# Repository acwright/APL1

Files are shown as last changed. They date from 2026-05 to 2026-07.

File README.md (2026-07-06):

APL1
====

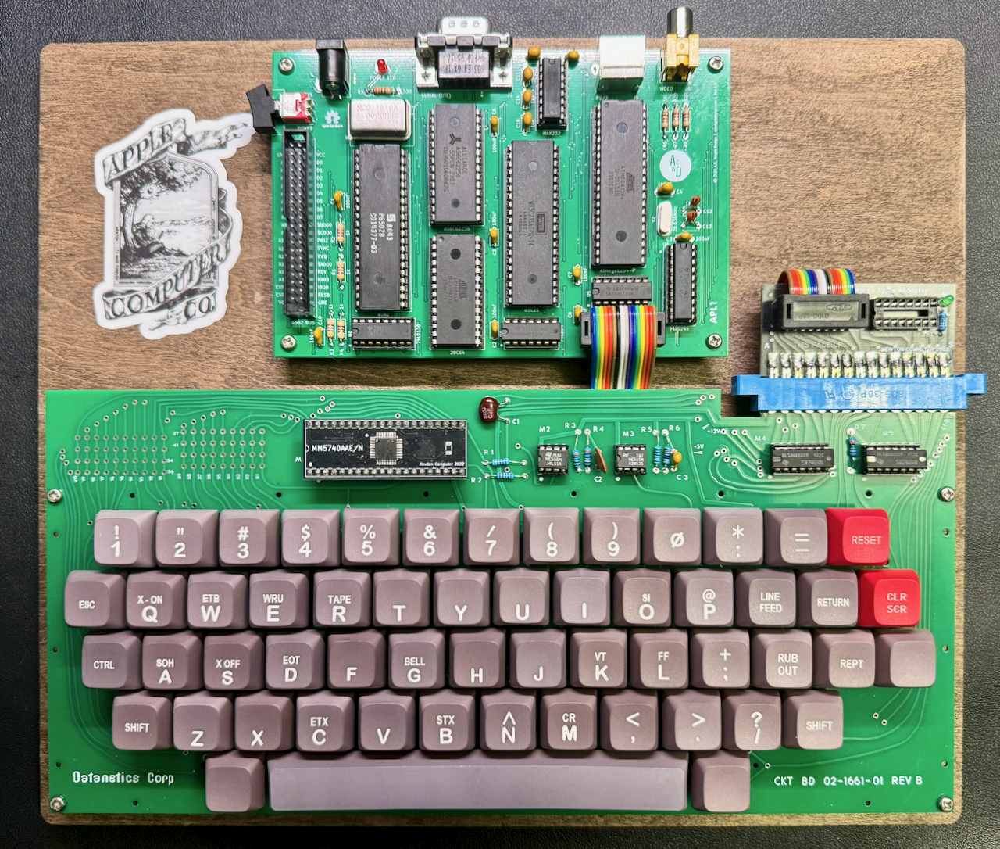
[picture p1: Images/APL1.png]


A homebrew **Apple 1** replica built around the **6502** microprocessor, with a modern microcontroller-based terminal that adds PS/2 keyboard and serial input alongside the original ASCII keyboard interface.

---

## Table of Contents

- [Overview](#overview)
- [Architecture](#architecture)
- [Hardware](#hardware)
  - [APL1 Board](#apl1-board)
    - [Revision History](#revision-history)
- [Firmware](#firmware)
  - [APL1 Controller](#apl1-controller)
  - [APL1 ROM](#apl1-rom)
  - [APL1 Terminal](#apl1-terminal)
- [CAD](#cad)
- [Production](#production)
- [Schematics](#schematics)
- [Libraries](#libraries)
- [Bill of Materials](#bill-of-materials)
- [License](#license)

---

## Overview

The **APL1** is a faithful recreation of the 1976 Apple 1 computer, rebuilt as an open-source KiCad project. It preserves the original 6502 + PIA architecture and the classic [WozMon](https://en.wikipedia.org/wiki/Woz_Monitor) firmware experience, while replacing the bulky discrete terminal section of the original with an ATmega1284 microcontroller. The MCU emulates the Apple 1 keyboard and display handshake exactly, but also exposes a PS/2 keyboard port and a serial terminal connection for modern convenience.

## Architecture

- **CPU**: MOS 6502 running at 1 MHz
- **RAM**: 32KB SRAM (AS6C62256)
- **ROM**: 8KB EEPROM (28C64) holding WozMon
- **PIA**: 65C21 — the Apple 1 keyboard/display interface
- **Terminal**: ATmega1284(P) controller emulating the original terminal handshake
- **Input**: Original ASCII keyboard header, PS/2 keyboard, and serial (RS-232) input
- **Output**: Serial terminal output, with composite video reserved for a future revision
- **Bus**: 16-bit address bus, 8-bit bidirectional data bus, standard 6502 control signals
- **Clock**: 1 MHz oscillator for the 6502; 28.63636 MHz crystal (8× NTSC colorburst) for the controller

## Hardware

This repository contains KiCad 7.0+ PCB designs for the APL1 board.

### APL1 Board
`Hardware/APL1/`

The single board hosting the 6502 CPU, memory, PIA, and the ATmega1284 terminal controller. Provides:

- **CPU**: 6502 running at 1 MHz
- **RAM**: 32KB SRAM (AS6C62256)
- **ROM**: 8KB EEPROM (28C64) preloaded with WozMon
- **PIA**: 65C21 keyboard/display interface (original Apple 1 footprint)
- **Terminal Controller**: ATmega1284(P) running APL1 Controller firmware
- **Keyboard buffer**: 74LS245 octal bus transceiver
- **Glue logic**: 74LS04, 74LS00, and 74LS138 address decoder
- **Serial**: MAX232 level shifter with DB-9 (DTE) connector
- **Input**: Original ASCII keyboard header and PS/2 keyboard connector
- **Video**: RCA composite video jack (reserved for a future firmware revision)
- **Reset**: Keyboard reset and clear controls handled by the controller
- **Power**: 5V DC via barrel jack, with power switch and indicator LED

#### Revision History

**Rev 1.1**

- Add 10k pull-down resistor `R9` for KBDCLR.
- Change pull-up resistors `R1-R4` from 1k to 4.7k.
- Add capacitor `C17` for bulk capacitance at power supply.

**Rev 1.0**

- Initial release.

## Firmware

This repository contains firmware for the terminal controller, the system ROM, and the desktop terminal application.

### APL1 Controller
`Firmware/APL1 Controller/`

[PlatformIO](https://platformio.org/)-based firmware for the ATmega1284(P) terminal controller. Provides:

- Faithful emulation of the Apple 1 keyboard and display handshake (DA / RDAB)
- Original ASCII keyboard pass-through via the 74LS245 buffer
- PS/2 keyboard input with a custom Set-2 ISR decoder mapped to Apple 1 ASCII
- Serial (RS-232) terminal input and output at 115200 8N1
- Control shortcuts for clear screen, reset, and throttle ("slow") mode
- Keyboard reset and clear button handling
- Composite video output hooks reserved for a future revision

See [Firmware/APL1 Controller/README.md](./Firmware/APL1%20Controller/README.md) for build, flash, and pin-map details.

### APL1 ROM
`Firmware/APL1 ROM/`

The system ROM image built from **WozMon**, Steve Wozniak's original Apple 1 monitor, assembled with the [cc65](https://cc65.github.io/) toolchain and burned to a 28C64 EEPROM.

See [Firmware/APL1 ROM/README.md](./Firmware/APL1%20ROM/README.md) for build and programming instructions.

### APL1 Terminal
`Firmware/APL1-Terminal/`

An [Electron](https://www.electronjs.org/) + [Vue 3](https://vuejs.org/) desktop application that provides a faithful CRT terminal experience for the APL1. Connects to the board over the DB-9 serial port at 115200 8N1 and renders output using the original Signetics 2513 character ROM glyphs. Provides:

- 40×24 character canvas rendered with the authentic Signetics 2513 font
- Selectable phosphor color: white, amber, or green
- CRT effects: phosphor glow, scanlines overlay, and screen flicker animation
- Serial port connection and disconnection (auto-detected ports)
- Keyboard input forwarded to the APL1 with Apple 1 control shortcuts (Ctrl+L clear, Ctrl+\ reset, Ctrl+T throttle)
- Built-in program loader with paced character/line sending for 20 bundled Wozmon programs
- Settings panel with per-character and per-line delay controls
- macOS (Apple Silicon DMG), Linux (AppImage / deb), and Windows (NSIS installer) distribution builds, all built locally from macOS

See [Firmware/APL1-Terminal/README.md](./Firmware/APL1-Terminal/README.md) for build and run instructions.

## CAD
`CAD/`

3D models and images for the APL1 board and its components.

## Production
`Production/`

JLCPCB-ready fabrication files, BOM, and component positions for PCB fabrication and assembly.

## Schematics
`Schematics/`

Schematics for the APL1 board.

## Libraries
`Libraries/`

Shared KiCad symbol and footprint libraries used across the APL1 hardware project.

## Bill of Materials

| Reference | Qty | Value | Description |
|---|-----|---|---|
| C1–C10 | 10 | 100nF | Disc Capacitor |
| C11, C14, C15, C16 | 4 | 1µF | Disc Capacitor |
| C12, C13 | 2 | 18pF | Disc Capacitor |
| C31 | 1 | 10uF | Electrolytic Capacitor 16v |
| D1 | 1 | POWER LED | 3.0mm Power LED |
| J2 | 1 | KEYBOARD | ASCII Keyboard Header (DIP-16) |
| J3 | 1 | SERIAL (DTE) | DB-9 Male |
| J4 | 1 | 5V DC | DC Barrel Jack |
| J5 | 1 | PS/2 | 6-pin Mini-DIN (KMDGX-6S-BS) |
| J6 | 1 | VIDEO | RCA Jack (PJRAN1X1U0XX) |
| R1–R4 | 4 | 4.7kΩ | 1/8W Resistor |
| R6 | 1 | 1kΩ | 1/8W Resistor |
| R5 | 1 | 330Ω | 1/8W Resistor |
| R7, R8 | 2 | 820Ω | 1/8W Resistor |
| R9 | 2 | 10kΩ | 1/8W Resistor |
| SW1 | 1 | POWER | SPDT Switch (400MSP1R6BLKM6QE) |
| U1 | 1 | 74LS04 | Hex Inverter |
| U2 | 1 | 6502 | 6502 CPU |
| U3 | 1 | 65C21 | PIA |
| U4 | 1 | AS6C62256 | 32KB SRAM |
| U5 | 1 | 74LS00 | Quad NAND |
| U6 | 1 | 74LS138 | 3-to-8 Decoder |
| U7 | 1 | 28C64 | 8KB EEPROM |
| U8 | 1 | 74LS245 | Octal Bus Transceiver |
| U9 | 1 | MAX232 | RS-232 Transceiver |
| U10 | 1 | ATmega1284-P | Terminal Controller MCU |
| Y1 | 1 | 1MHz | DIP-14 Oscillator |
| Y2 | 1 | 28.636MHz | Crystal |

## License

Hardware designs are released under the [CERN Open Hardware Licence Version 2 – Permissive](https://ohwr.org/cern_ohl_p_v2.txt).

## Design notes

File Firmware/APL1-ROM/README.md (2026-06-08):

APL1 ROM
========

ROM for the [A.C. Wright APL1 project](https://github.com/acwright/APL1).

## Prerequisites

### Install cc65 Toolchain

The cc65 toolchain provides the assembler and linker needed to build 6502 assembly code.

macOS (using Homebrew):
```bash
brew install cc65
```

Linux (Debian/Ubuntu):
```bash
sudo apt-get install cc65
```

Other platforms: See [cc65 documentation](https://cc65.github.io/)

### Optional: Install minipro (for EEPROM burning)

Only required if you plan to program an AT28C256 EEPROM chip:
```bash
brew install minipro
```

## Building

Build the ROM image:
```bash
make
```

This generates:
- `WOZMON.bin` - 32KB ROM image ($8000-$FFFF)
- `WOZMON.lst` - Assembly listing file for debugging

## Verification

View the generated binary as hex dump:
```bash
make view
```

## Programming EEPROM

To burn the ROM to an AT28C256 EEPROM chip using a TL866 programmer:
```bash
make eeprom
```

**Note:** This requires a TL866 (or compatible) programmer and the minipro software.

## Cleaning Build Artifacts

Remove generated files:
```bash
make clean
```

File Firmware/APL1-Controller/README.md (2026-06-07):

# APL1 Controller Firmware

## Overview

Firmware for the ATmega1284(P) that replicates the Apple-1 terminal circuitry and extends it with PS/2 keyboard and serial (USB/UART) input. The microcontroller sits between a PS/2 keyboard, a serial terminal, and the original 6521 PIA, faithfully emulating the Apple-1 keyboard and display handshake while adding modern input options. Composite video output is reserved for a future phase.

The crystal is 28.63636 MHz (8× NTSC colorburst), overclocked beyond the 1284's 20 MHz rating to allow cycle-accurate composite video generation in a later revision. All current functionality runs well within safe operating margins at 3.3–5 V.

---

## Hardware

| Item | Value |
|---|---|
| MCU | ATmega1284P (or ATmega1284), DIP-40 |
| Clock | External full-swing crystal, 28.63636 MHz |
| F_CPU | 28 636 363 Hz |
| Framework | Arduino via PlatformIO |
| Programmer | minipro (TL866 / T48) |
| PIA | MOS 6521 (Apple-1 original footprint) |
| Keyboard buffer | 74LS245 octal bus transceiver |

---

## Pin Map

### PORTA – Keyboard data output to PIA (PA0–PA7)

| Pin | Signal | Direction | Description |
|-----|---|---|---|
| PA0–PA6 | KBD\[6:0\] | Output (during key inject) | Apple-1 ASCII data to PIA PA0–PA6 |
| PA7 | STROBE / CA1 | Output (during key inject) | Rising edge latches key into PIA |

Idle state: all Hi-Z inputs (74LS245 drives the bus when not injecting).

### PORTB – Display data input from PIA (PB0–PB7)

| Pin | Signal | Direction | Description |
|-----|---|---|---|
| PB0–PB6 | DISP\[6:0\] | Input | 7-bit ASCII from PIA PB0–PB6 |
| PB7 | DA (active-high) | Input | Display Available – high when 6502 has written a char (PIA CB2 inverted by U1) |

### PORTC – Video DAC + control

| Pin | Signal | Direction | Description |
|-----|---|---|---|
| PC0–PC2 | VIDEO\_DAC | Output (LOW) | Composite video DAC (1 kΩ / 820 Ω / 820 Ω) – deferred |
| PC3–PC6 | — | Input w/ pullup | Unused, held at defined state |
| PC7 | RDAB / CB1 | Output | Active-low pulse clears DA flag in PIA; idle HIGH |

### PORTD – UART + PS/2 + control

| Pin | Signal | Direction | Description |
|-----|---|---|---|
| PD0 | RXD | Input | UART receive (115200 8N1) |
| PD1 | TXD | Output | UART transmit (115200 8N1) |
| PD2 | PS2CLK / INT0 | Input w/ pullup | PS/2 clock – triggers INT0 ISR on falling edge |
| PD3 | PS2DATA | Input w/ pullup | PS/2 data |
| PD4 | KBDRESB (active-low) | Input w/ pullup | Keyboard reset button – resets 6502 + PS/2 state |
| PD5 | KBDCLR (active-high) | Input (external 10 kΩ pull-down to GND required) | Keyboard clear button – sends ANSI clear to serial |
| PD6 | KBDENB (active-low) | Output | 74LS245 OE – LOW=buffer enabled, HIGH=disabled during key inject |
| PD7 | RESB (active-low) | Output | 6502 reset line – held LOW at power-on then released |

---

## Features

### Display path (6502 → serial)
The 6502 writes a character to PIA Port B and asserts DA. The PIA's CB2 handshake output is active-low, but an external 74HC04 inverter (U1) feeds it to PB7, so the line is active-**high** at the 1284. The 1284 detects PB7 HIGH, reads PB0–PB6, then pulses RDAB (CB1) low to clear DA. The 7-bit ASCII value is forwarded to the serial port. Bare CR (0x0D) is translated to CR+LF for terminal compatibility.

### ASCII keyboard pass-through
The original ASCII keyboard is connected via a 74LS245 buffer (KBDENB, active-low). When no injection is in progress the buffer is enabled and the keyboard drives the PIA directly, preserving full compatibility with the original Apple-1 circuit.

### PS/2 keyboard input
A custom ISR-based Set-2 decoder handles the 11-bit PS/2 frame (start / 8 data LSB-first / odd parity / stop) on INT0 (falling edge). Decoded make codes are mapped to Apple-1 ASCII (uppercase, bit 7 set) using tables in flash. Supported:
- All printable US-layout keys (unshifted and shifted)
- **Enter** → 0x8D (Apple-1 CR)
- **Backspace** → 0xDF (Apple-1 `_` rubout)
- **ESC** → 0x9B
- Left/Right Shift, Left Ctrl, Right Ctrl (via E0 prefix), Left/Right Alt tracked
- Caps Lock ignored (Apple-1 is uppercase-only)
- **Ctrl+L** → clear screen (ANSI ESC\[2J ESC\[H to serial)
- **Ctrl+\\** → reset 6502 (assert RESB low pulse)
- **Ctrl+T** → toggle throttle / “slow” mode (original Apple-1 output speed)
- **Ctrl+Alt+Del** → reset 6502

### Serial input (PC → 6502)
Characters received over the serial port are uppercased, bit 7 set, and injected into the PIA via `sendKey()`. Control shortcuts:
- **Ctrl+L** (0x0C) → clear screen
- **Ctrl+\\** (0x1C) → reset 6502
- **Ctrl+T** (0x14) → toggle throttle / “slow” mode

### Throttle (“slow”) mode
The serial path is far faster than the original Apple-1 because `Serial.write()` is UART-buffered — the 6502 barely waits on the DA flag before emitting the next character. Throttle mode restores the original “feel” by emulating the slow video terminal: before clearing DA, the firmware keeps the flag asserted for `SLOW_CHAR_DELAY_MS` (16 ms ≈ 60 characters/second), forcing the 6502 to spin in WozMon’s `BIT DSP / BMI ECHO` loop just as it did against the real hardware. The throttle is applied via this deliberate delay rather than the baud rate, so it is independent of the 115200 8N1 link.

- Toggled at runtime by **Ctrl+T** from either the serial terminal or the PS/2 keyboard (no reflash needed).
- Default is **full speed** (`slowMode = false`); the toggle is silent and consumed (not forwarded to the 6502).
- Tune the rate by editing `SLOW_CHAR_DELAY_MS` in `src/main.cpp` (8 ms ≈ 125 cps, 16 ms ≈ 60 cps, 33 ms ≈ 30 cps).

### Key injection
`sendKey(ascii)` disables the 74LS245 (KBDENB HIGH), drives PA0–PA6 with the 7-bit ASCII value, generates a rising edge on PA7 (STROBE → CA1) to latch the key into the PIA, then returns PA to Hi-Z and re-enables the buffer. The entire sequence takes < 30 µs.

### DA / RDAB handshake
Matches the original Apple-1 terminal circuit:
1. 6502 writes character to PIA Port B → CB2 goes low; the 74HC04 (U1) inverts it so DA is asserted **high** on PB7
2. 1284 detects DA high, reads the data, pulses RDAB (CB1) low ~5 µs
3. PIA clears CB2 (DA returns low); 6502 can write the next character

### Control buttons
Both buttons are debounced (20 ms):
- **KBDRESB** (PD4, active-low, internal pull-up) – asserts RESB low for 10 ms (resets 6502) and clears PS/2 decoder state
- **KBDCLR** (PD5, active-**high**, external 10 kΩ pull-down to GND required) – sends ANSI clear sequence to serial (video framebuffer clear deferred)

> **Hardware note:** The ATmega1284 has no internal pull-down resistors. PD5 **must** have an external ~10 kΩ resistor to GND. Without it the pin floats, making the button unreliable and potentially triggering a spurious clear on startup.

---

## Build & Flash

### Prerequisites
- [PlatformIO](https://platformio.org/) (CLI or VS Code extension)
- [minipro](https://gitlab.com/DavidGriffith/minipro) with a TL866 or T48 programmer

### Build

```sh
pio run                  # build both envs
pio run -e atmega1284p   # build only the 1284P variant
```

### Flash (code + fuses in one step)

```sh
pio run -e atmega1284p --target upload
```

The upload command is:
```sh
minipro -p "ATMEGA1284P@DIP40" -c code -w firmware.hex && \
minipro -p "ATMEGA1284P@DIP40" -c config -w fuses.cfg --fuses
```

For the non-P variant use env `atmega1284` and `-p "ATMEGA1284@DIP40"`.

### Fuse values

| Fuse | Value | Notes |
|---|---|---|
| lfuse | 0xF7 | Full-swing crystal oscillator (CKSEL=0111), CKDIV8 off, SUT slow-rising power |
| hfuse | 0xFF | All defaults (JTAG on, no bootloader, Brown-out disabled) |
| efuse | 0xFF | — |
| lock | 0xFF | No lock bits |

> **Warning:** setting lfuse 0xF7 requires an external crystal. Attempting to read back fuses without a crystal present will leave the device unresponsive; use the programmer's external-clock option to recover.

---

## Project Status

| Phase | Description | Status |
|---|---|---|
| 1 | Build config & timing (F_CPU, fuses) | ✅ Done |
| 2 | Pin defs & init, power-on reset | ✅ Done |
| 3 | Display path (PIA → serial) | ✅ Done |
| 4 | Key injection (`sendKey`) | ✅ Done |
| 5 | Serial input + control shortcuts | ✅ Done |
| 6 | PS/2 ISR decoder + Set-2 keymap | ✅ Done |
| 7 | KBDRESB / KBDCLRB control signals | ✅ Done |
| 8 | README | ✅ Done |
| 9 | Hardware verification | ⏳ Pending |
| — | Composite video | 🔮 Future |

---

## Future: Composite Video

- `putDisplayChar()` and `clearScreen()` already contain hooks for a video framebuffer.
- PC0–PC2 are wired to a resistor-ladder DAC for composite output.
- A timer ISR will generate the video signal; the main loop is kept non-blocking to avoid tearing.

---

## License

See the main repository LICENSE file for licensing information.

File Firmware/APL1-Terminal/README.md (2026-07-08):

APL1 Terminal
=============

Desktop terminal application for the [A.C. Wright APL1 project](https://github.com/acwright/APL1).

An [Electron](https://www.electronjs.org/) + [Vue 3](https://vuejs.org/) app that provides a faithful CRT terminal experience for the APL1. It connects to the board over the DB-9 serial port at 115200 8N1 and renders output using the original Signetics 2513 character ROM glyphs on an authentic-looking monitor bezel.

---

## Features

- **Authentic display** — 40×24 character canvas rendered from Signetics 2513 ROM glyph data
- **Phosphor colors** — switchable white, amber, or green phosphor
- **CRT effects** — phosphor glow, scanlines overlay, and screen flicker (individually toggleable)
- **Serial connection** — auto-discovers ports; connects at 115200 8N1
- **Keyboard input** — keystrokes forwarded to the APL1 with Apple 1 control shortcuts
- **Program loader** — paced sending of Wozmon programs via two input modes: local file upload or pasted text; configurable per-character and per-line delays
- **Persistent settings** — port selection, display options, and pacing delays saved across sessions

---

## Keyboard Shortcuts

| Shortcut | Action |
|---|---|
| Ctrl+L | Clear screen (ANSI clear forwarded to APL1) |
| Ctrl+\ | Reset the 6502 |
| Ctrl+T | Toggle throttle ("slow") mode on the controller |
| F1 / ⚙ button | Open / close settings panel |
| Escape | Close open overlay panel |

---

## Send Program Panel

The Send Program panel is opened by clicking the SEND button on the monitor control panel. It provides two tabs for loading Wozmon programs:

| Tab | Description |
|-----|---|
| **File** | Browse for a local Wozmon-formatted `.txt` or `.woz` file. The first `XXXX:` address in the file is detected automatically and shown as a run command hint (e.g. `0280R`). |
| **Paste** | Paste Wozmon hex lines directly into a text area. The start address is detected in real time from the pasted content and shown as a run command hint. |

Both tabs share the same paced-send engine (configurable per-character and per-line delays), the same progress bar, and the SEND / CANCEL controls. Comment lines beginning with `;` and blank lines are stripped before sending. Each line is transmitted character-by-character with bit 7 set, followed by a carriage return (0x8D).

---

## Prerequisites

- [Node.js](https://nodejs.org/) 18 or later
- npm 9 or later

Install dependencies:

```bash
npm install
```

---

## Development

Start the app in development mode with hot reload:

```bash
npm run dev
```

Type-check without building:

```bash
npm run typecheck
```

---

## Building

Compile the app (outputs to `out/`):

```bash
npm run build
```

### Distribution

Distribution packages are built locally on macOS. Each platform has its own prerequisites:

| Platform | Prerequisite |
|---|---|
| **macOS** | Xcode, a valid **Developer ID Application** certificate in Keychain |
| **Linux** | Docker (electron-builder runs inside `electronuserland/builder`) |
| **Windows** | Wine — `brew install --cask wine-stable` |

Before building macOS targets, export your notarization credentials (or add them to `~/.zshrc`):

```bash
export APPLE_ID="your@apple.id"
export APPLE_APP_SPECIFIC_PASSWORD="xxxx-xxxx-xxxx-xxxx"
export APPLE_TEAM_ID="XXXXXXXXXX"
```

Build commands:

```bash
# macOS (Apple Silicon DMG — signed and notarized)
npm run dist:mac

# Linux (AppImage + deb, x64 — requires Docker)
npm run dist:linux

# Windows (NSIS installer, x64 — requires Docker)
npm run dist:win

# All three platforms
npm run dist
```

Artifacts are written to the `dist/` directory. After tagging a release, upload the artifacts to the corresponding GitHub release manually.

> **Note — Linux builds:** `dist:linux` runs entirely inside Docker. It uses a named Docker volume (`apl1-terminal-linux-modules`) to keep Linux-compiled `node_modules` isolated from the macOS working copy. The first run pulls the Docker image and compiles native modules; subsequent runs reuse the cached volume and are significantly faster.

---

## Project Structure

```
APL1-Terminal/
├── src/
│   ├── main/
│   │   ├── index.ts         # Electron main process, IPC handlers, window setup
│   │   ├── serial.ts        # SerialService — serial port management (115200 8N1)
│   │   └── settings.ts      # SettingsService — persistent settings via JSON
│   ├── preload/
│   │   └── index.ts         # Context bridge — exposes api.serial, api.settings, api.window, and api.app to renderer
│   ├── renderer/src/
│   │   ├── App.vue           # Root component — keyboard handling, overlay management
│   │   ├── components/
│   │   │   ├── MonitorFrame.vue    # Sanyo monitor bezel skin with control panel
│   │   │   ├── TerminalCanvas.vue  # 40×24 canvas screen with CRT effects
│   │   │   ├── SettingsPanel.vue   # Serial port selector and display settings
│   │   │   ├── ProgramSelect.vue   # Program loader with paced sending
│   │   │   └── ColorKnob.vue       # Phosphor color selector knob
│   │   ├── terminal/
│   │   │   ├── buffer.ts     # 40×24 character buffer
│   │   │   ├── parser.ts     # Byte-stream parser (Apple 1 ASCII → buffer)
│   │   │   ├── painter.ts    # Canvas renderer with phosphor glow
│   │   │   └── glyphAtlas.ts # Glyph atlas built from Signetics 2513 ROM data
│   │   └── assets/
│   │       └── signetics2513.ts  # Signetics 2513 character ROM (64 glyphs, 5×7 px)
│   └── shared/
│       └── types.ts          # Shared types and IPC channel constants
├── electron-builder.yml      # Distribution build configuration
├── electron.vite.config.ts   # electron-vite build configuration
└── package.json
```

---

## Settings

Settings are persisted to `<userData>/settings.json` and restored on next launch.

| Setting | Default | Description |
|---|---|---|
| `port` | `null` | Last-used serial port path |
| `phosphorColor` | `green` | Phosphor color: `white`, `amber`, or `green` |
| `crtEffects` | `true` | Master toggle for all CRT effects |
| `scanlines` | `true` | Horizontal scanlines overlay |
| `flicker` | `true` | Subtle screen flicker animation |
| `charDelay` | `10` ms | Delay between characters when sending a program |
| `lineDelay` | `60` ms | Delay between lines when sending a program |

---

## Changelog

### 1.2.0 — 2026-07-07

- **Removed built-in software library** — the bundled program catalog (Library tab and `software/` folder) has been removed in preparation for a future online repository and API.
- Send Program panel now has two tabs (File / Paste) instead of three.

### 1.1.0 — 2026-07-06

- **Send Program — File tab**: browse for any local Wozmon-formatted `.txt` or `.woz` file and send it with the paced-send engine.
- **Send Program — Paste tab**: paste Wozmon hex lines directly into a text area for immediate sending.
- **Auto run-command detection**: the File and Paste tabs scan the program content for the first `XXXX:` address line and display a Wozmon run-command hint (e.g. `0280R`) automatically.
- Send Program panel redesigned with a two-tab layout (File / Paste); both tabs share the progress bar, SEND/CANCEL controls, and not-connected warning.

### 1.0.0 — Initial release

- 40×24 CRT terminal with Signetics 2513 ROM glyphs.
- Phosphor color selector (white, amber, green) and CRT effects (glow, scanlines, flicker).
- Serial connection at 115200 8N1 with auto port discovery.
- Bundled library of 20 Wozmon programs with paced sending via Send Program panel.
- Persistent settings saved across sessions.

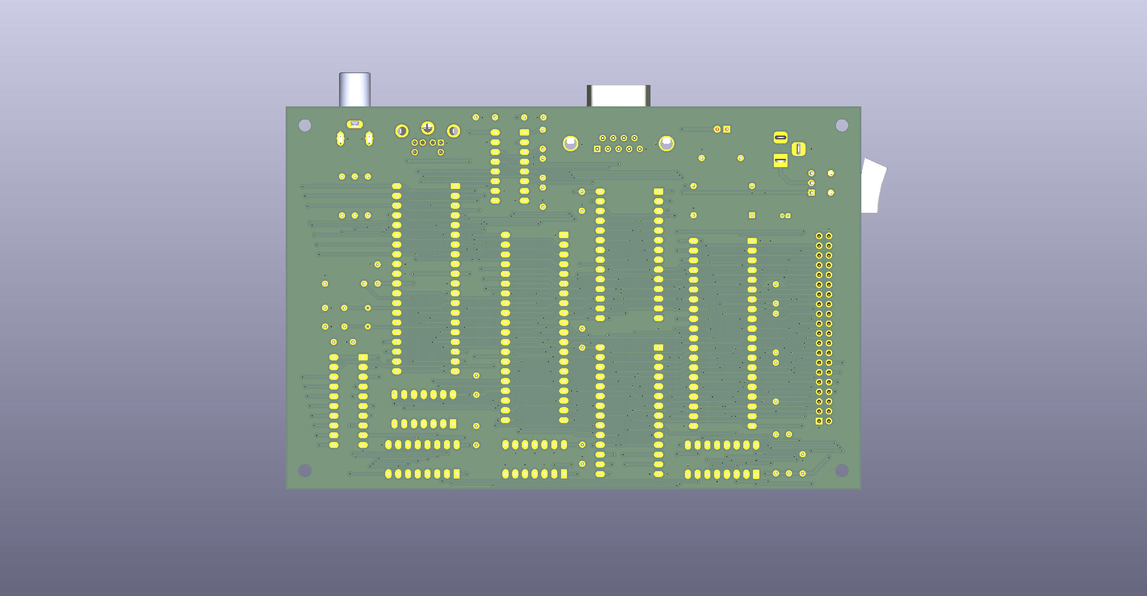
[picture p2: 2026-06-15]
CAD/Images/APL1/Rev 1.1/Back.png

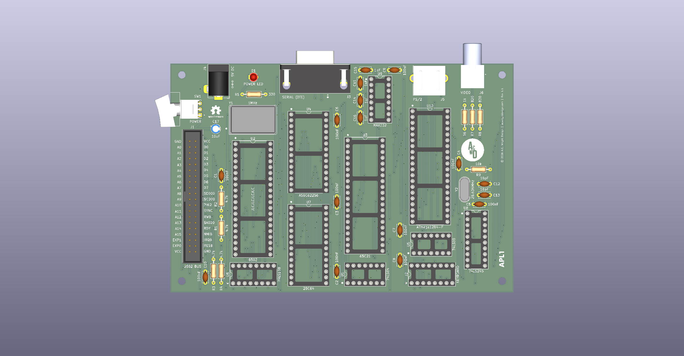
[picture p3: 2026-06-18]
CAD/Images/APL1/Rev 1.1/Front.png

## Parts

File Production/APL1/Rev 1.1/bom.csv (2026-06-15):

Designator | Footprint | Quantity | Value | LCSC Part #
C1, C10, C2, C3, C4, C5, C6, C7, C8, C9 | C_Disc_D5.0mm_W2.5mm_P5.00mm | 10 | 100nF
C11, C14, C15, C16 | C_Disc_D5.0mm_W2.5mm_P5.00mm | 4 | 1uF
C12, C13 | C_Disc_D5.0mm_W2.5mm_P5.00mm | 2 | 18pF
C17 | CP_Radial_D4.0mm_P1.50mm | 1 | 10uF
D1 | LED_D3.0mm | 1 | POWER LED
J2 | DIP-16_W7.62mm_Socket_LongPads | 1 | KEYBOARD
J3 | DSUB-9_Pins_Horizontal_P2.77x2.84mm_EdgePinOffset7.70mm_Housed_MountingHolesOffset9.12mm | 1 | SERIAL (DTE) | D09P33E4GX00LF
J4 | BarrelJack_Horizontal | 1 | 5V DC
J5 | KMDGX-6S-BS | 1 | PS/2
J6 | SWITCHCRAFT_PJRAN1X1U0XX | 1 | VIDEO
R1, R2, R3, R4 | R_Axial_DIN0207_L6.3mm_D2.5mm_P10.16mm_Horizontal | 4 | 4.7k
R5 | R_Axial_DIN0207_L6.3mm_D2.5mm_P10.16mm_Horizontal | 1 | 330
R6 | R_Axial_DIN0207_L6.3mm_D2.5mm_P10.16mm_Horizontal | 1 | 1k
R7, R8 | R_Axial_DIN0207_L6.3mm_D2.5mm_P10.16mm_Horizontal | 2 | 820
R9 | R_Axial_DIN0207_L6.3mm_D2.5mm_P10.16mm_Horizontal | 1 | 10k
SW1 | SW_400MSP1R6BLKM6QE | 1 | POWER
U1 | DIP-14_W7.62mm_Socket_LongPads | 1 | 74LS04
U10 | DIP-40_W15.24mm_Socket_LongPads | 1 | ATmega1284-P
U2 | DIP-40_W15.24mm_Socket_LongPads | 1 | 6502
U3 | DIP-40_W15.24mm_Socket_LongPads | 1 | 65C21
U4 | DIP-28_W15.24mm_Socket_LongPads | 1 | AS6C62256
U5 | DIP-14_W7.62mm_Socket_LongPads | 1 | 74LS00
U6 | DIP-16_W7.62mm_Socket_LongPads | 1 | 74LS138
U7 | DIP-28_W15.24mm_Socket_LongPads | 1 | 28C64
U8 | DIP-20_W7.62mm_Socket_LongPads | 1 | 74LS245
U9 | DIP-16_W7.62mm_Socket_LongPads | 1 | MAX232
Y1 | Oscillator_DIP-14 | 1 | 1MHz
Y2 | Crystal_HC49-U_Vertical | 1 | 28.636MHz

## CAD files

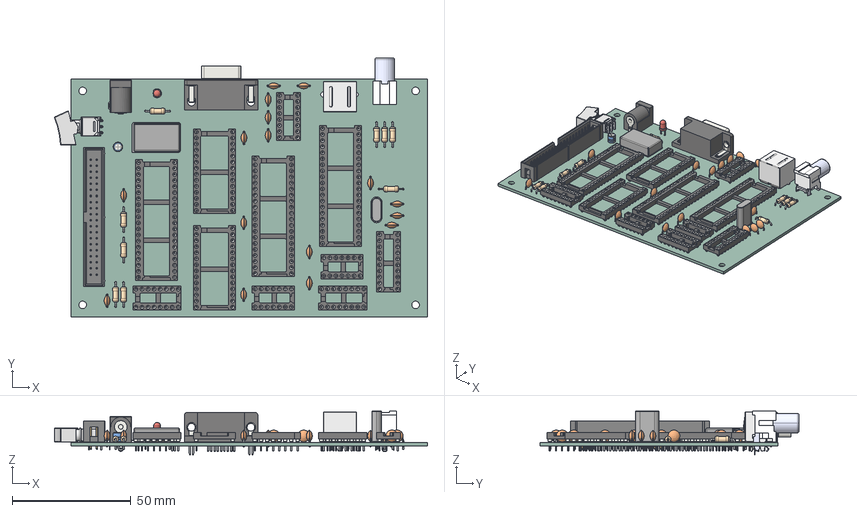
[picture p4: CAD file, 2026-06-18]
CAD/Models/APL1/Rev 1.1/APL1.step
156.8 x 108.8 x 18.5 mm
6120xx21621_PIN x 40
C_Disc_D50mm_W25mm_P500mm x 16
R_Axial_DIN0207_L63mm_D25mm_P1016mm_Horizontal x 9
DIP_16_W762mm_Socket x 3
DIP_14_W762mm_Socket x 2
KMDGX-6S-BS
DIP_28_W1524mm_Socket x 2
Oscillator_DIP-14
DIP_40_W1524mm_Socket x 3
BarrelJack_Horizontal
LED_D3.0mm
DSUB-9_Pins_Horizontal_P2.77x2.84mm_EdgePinOffset7.70mm_Housed_ MountingHolesOffset9.12mm
CP_Radial_D40mm_P150mm
PJRAN1X1U04X-edit
Crystal_HC49-U_Vertical
DIP_20_W762mm_Socket
P:\E-Switch Secure\3D_MODELS_STP_FORMAT\400MSPxR6xxxM6xE.stp
APL1_PCB

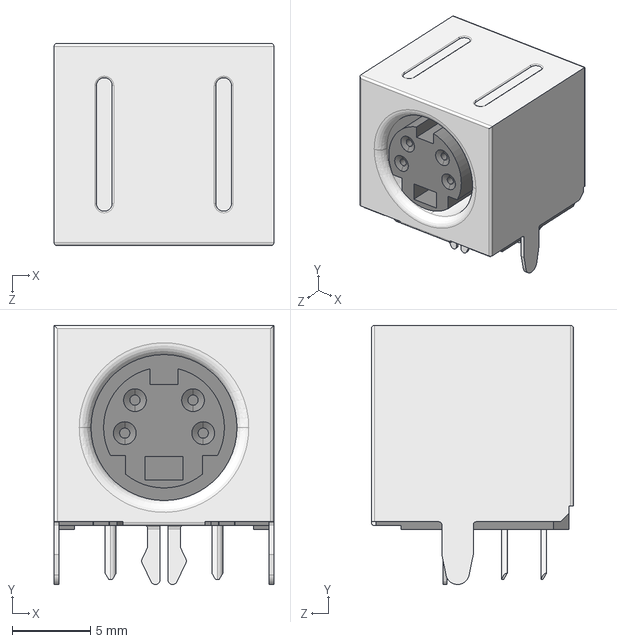
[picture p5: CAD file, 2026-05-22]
Models/KMDGX-6S-BS.step
14.0 x 16.5 x 12.9 mm

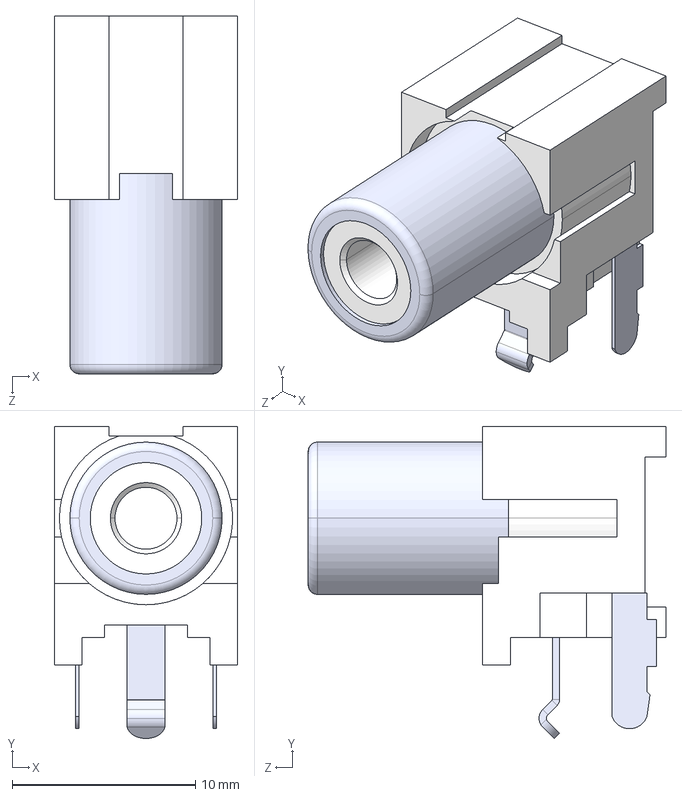
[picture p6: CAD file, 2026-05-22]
Models/PJRAN1X1U0XX.step
10.0 x 17.0 x 19.5 mm

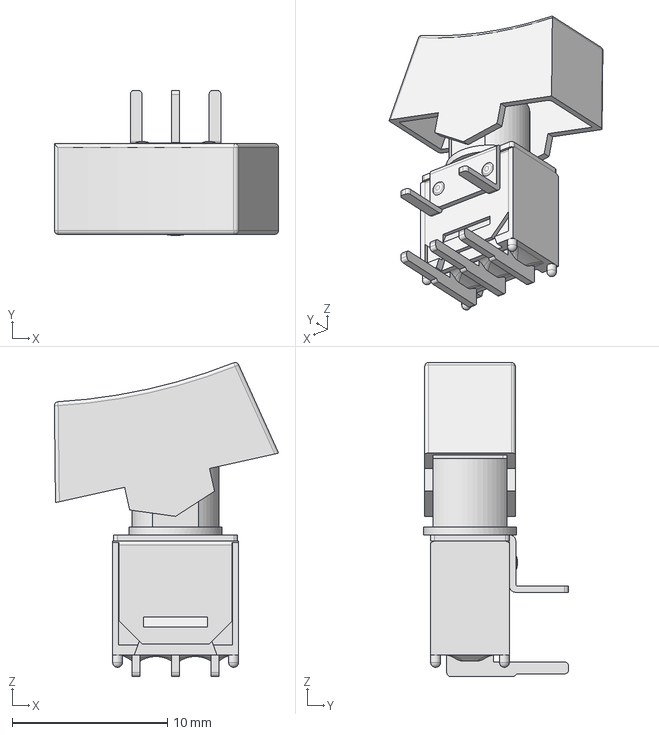
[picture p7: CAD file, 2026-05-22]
Models/400MSP1R6BLKM6QE.step
14.5 x 9.35 x 20.2 mm

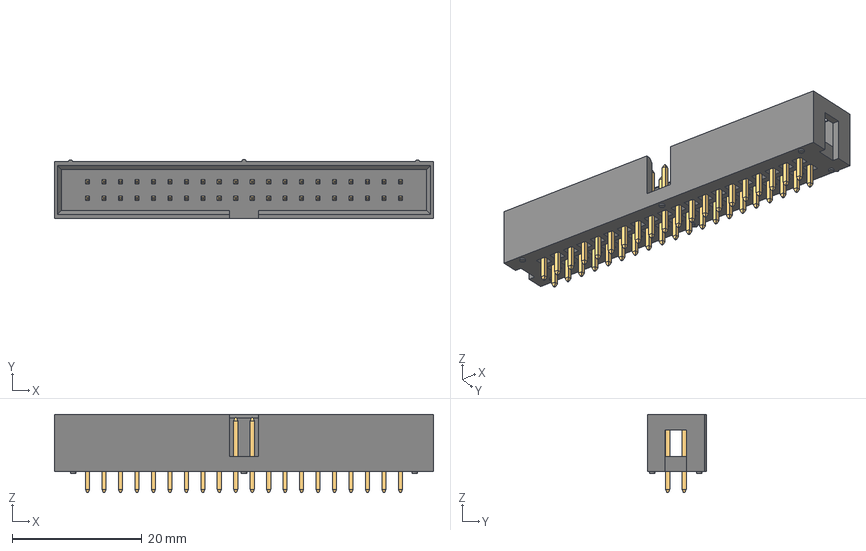
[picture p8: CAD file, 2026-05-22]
Models/61204021621.step
58.5 x 9.18 x 12.1 mm
6120xx21621_PIN x 40

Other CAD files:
CAD/Models/APL1/Rev 1.0/APL1.step

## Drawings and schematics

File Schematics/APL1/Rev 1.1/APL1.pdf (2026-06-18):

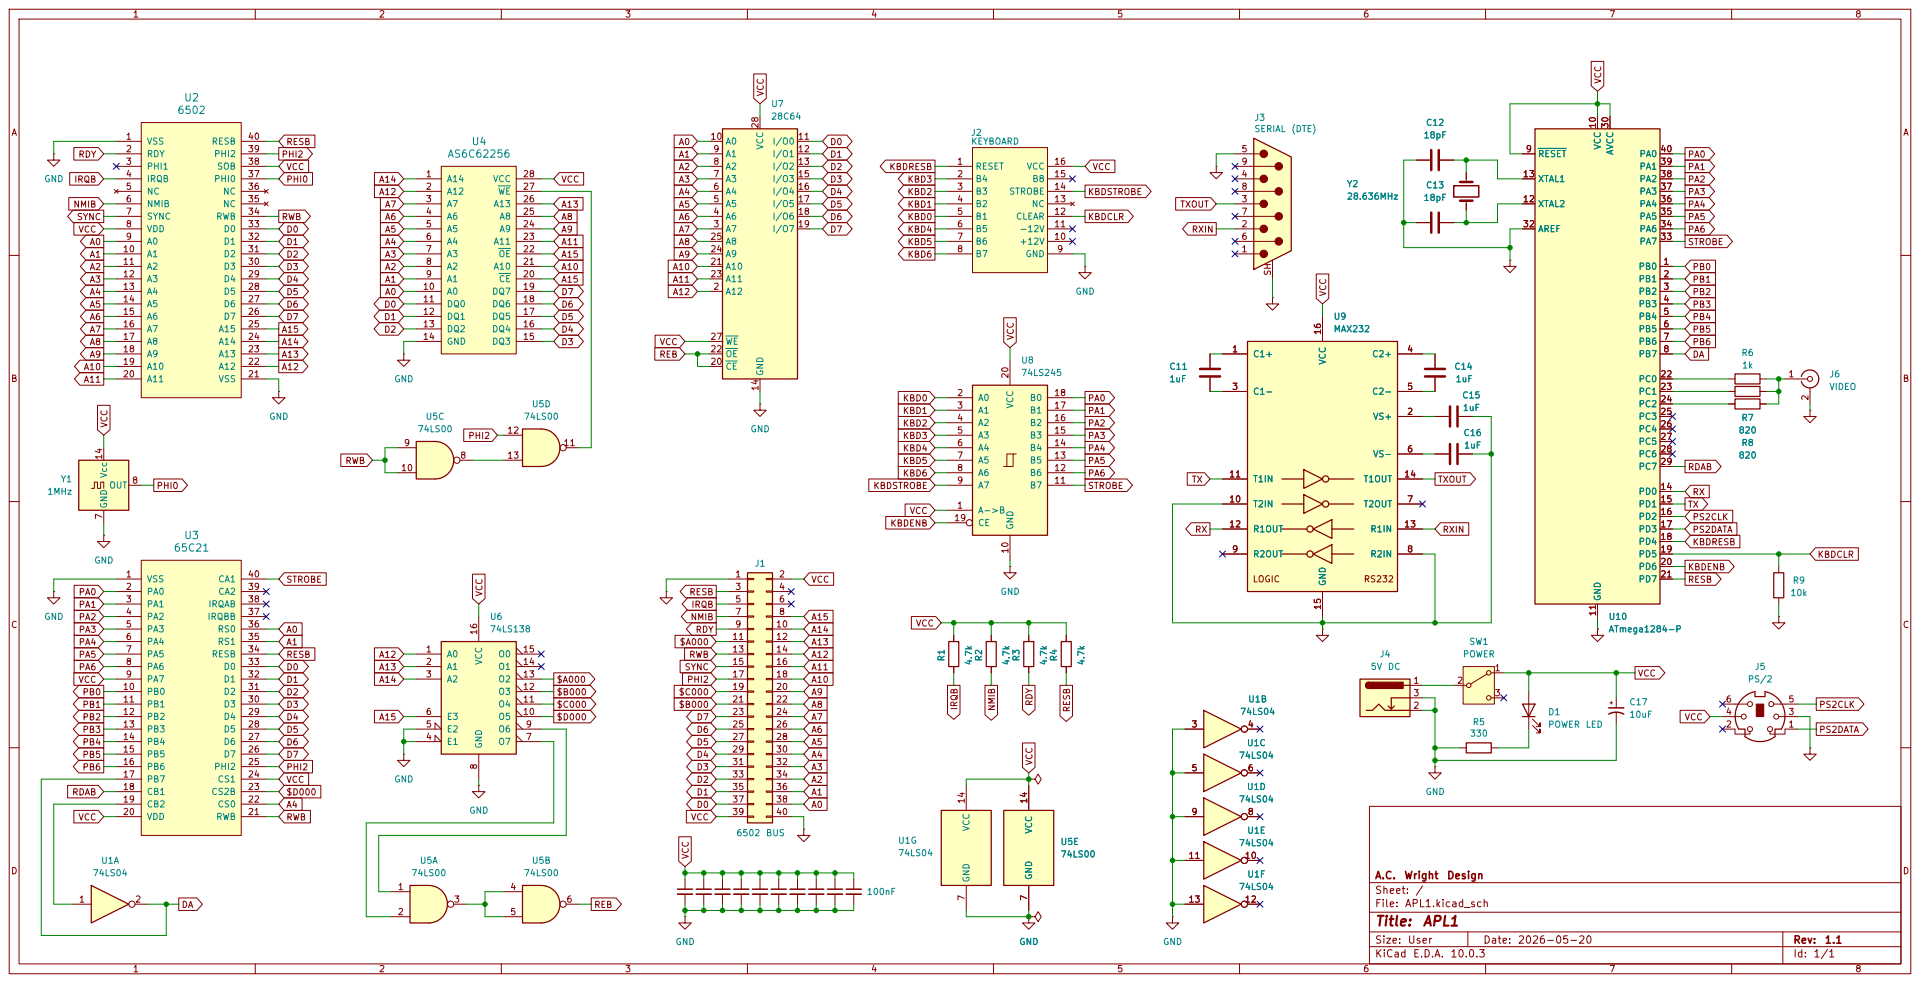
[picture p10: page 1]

Size: User | Rev: 1.1
KiCad E.D.A. 10.0.3 | Id: 1/1

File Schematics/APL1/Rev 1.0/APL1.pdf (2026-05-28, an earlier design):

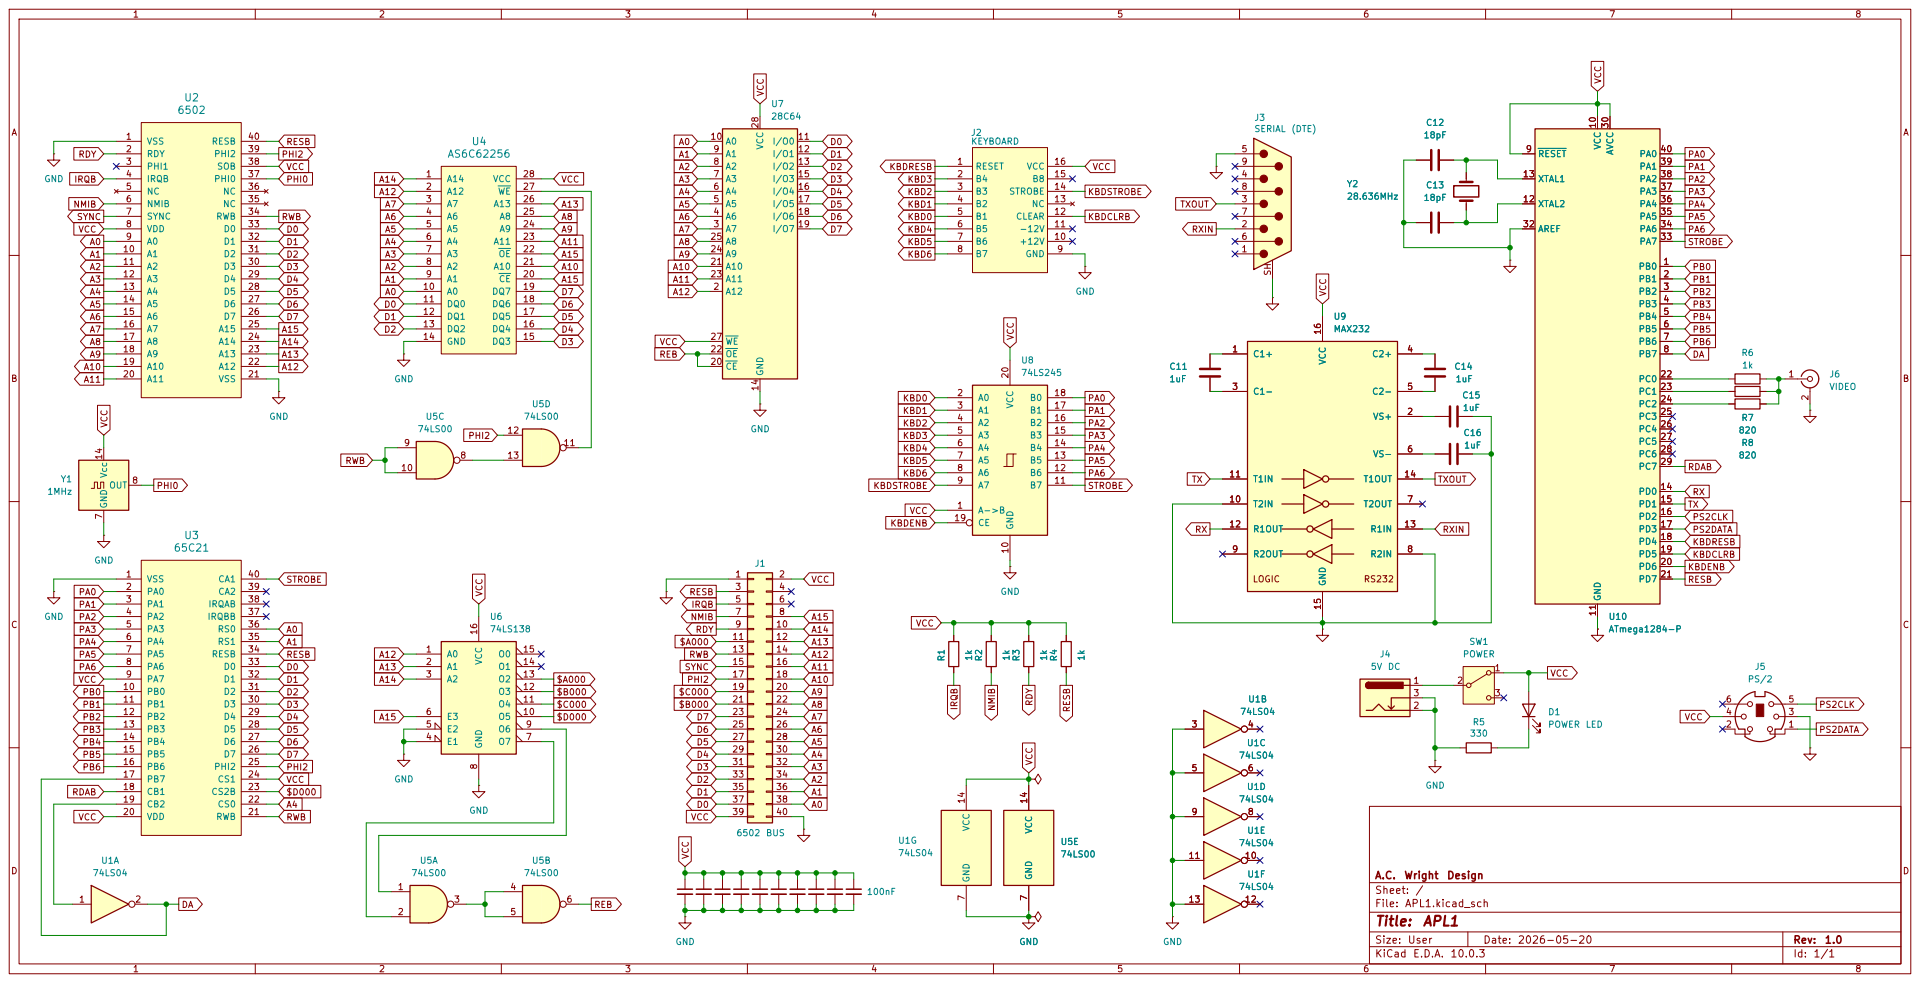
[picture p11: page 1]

Size: User | Rev: 1.0
KiCad E.D.A. 10.0.3 | Id: 1/1

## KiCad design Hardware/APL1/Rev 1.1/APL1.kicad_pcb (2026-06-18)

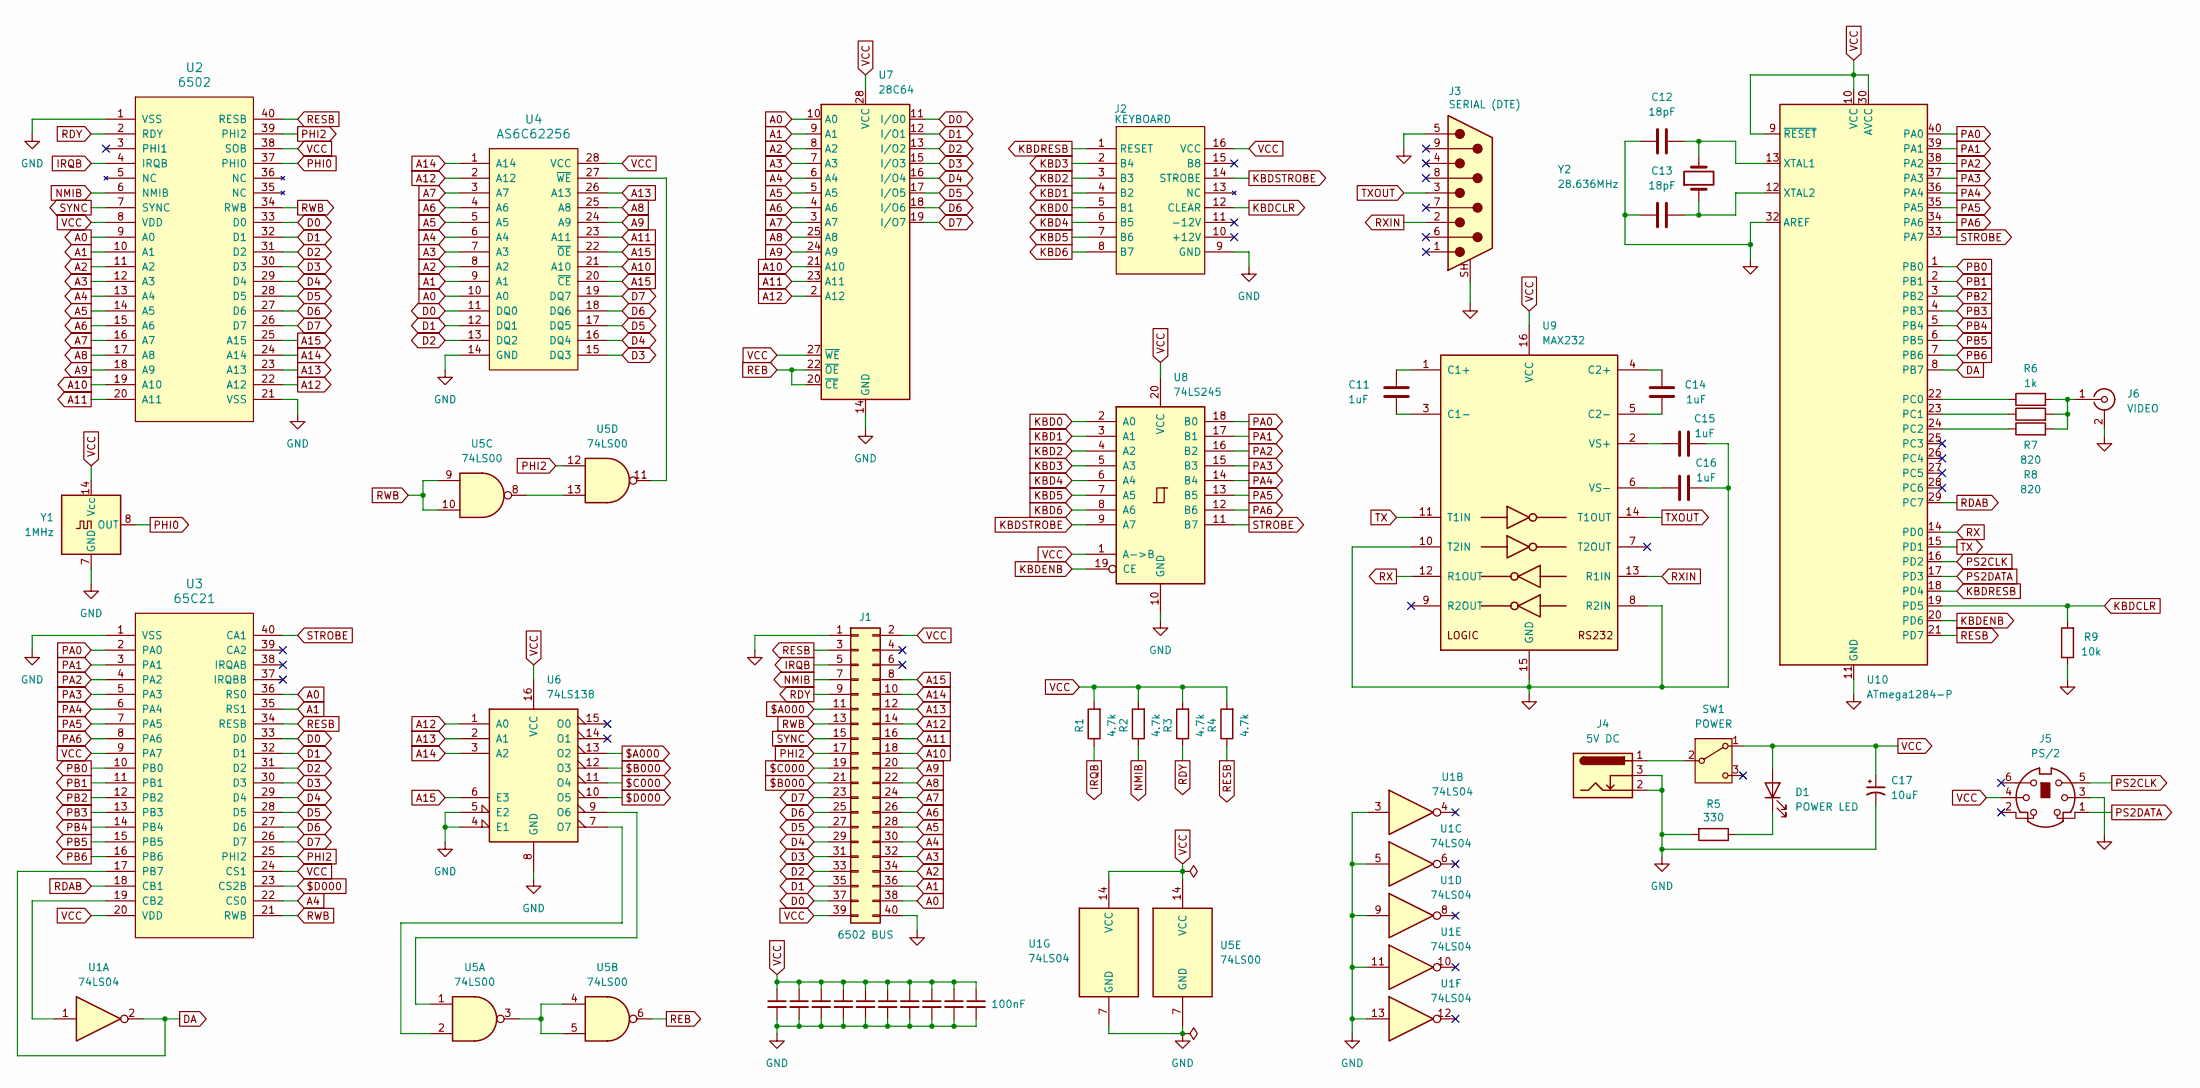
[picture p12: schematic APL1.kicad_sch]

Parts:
C1, C2, C3, C4, C5, C6, C7, C8, C9, C10: 100nF; C_Disc_D5.0mm_W2.5mm_P5.00mm
C11, C14, C15, C16: 1uF; C_Disc_D5.0mm_W2.5mm_P5.00mm
C12, C13: 18pF; C_Disc_D5.0mm_W2.5mm_P5.00mm
C17: 10uF; CP_Radial_D4.0mm_P1.50mm
D1: POWER LED; LED_D3.0mm; Digikey 732-5008-ND
J1: 6502 BUS; 6502 Bus Connector
J2: KEYBOARD; DIP-16_W7.62mm_Socket_LongPads
J3: SERIAL (DTE); DSUB-9_Pins_Horizontal_P2.77x2.84mm_EdgePinOffset7.70mm_Hou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; MPN D09P33E4GX00LF; Digikey 609-1481-ND
J4: 5V DC; BarrelJack_Horizontal; Digikey 2073-DCJ200-10-A-K1-K-ND
J5: PS/2; KMDGX-6S-BS
J6: VIDEO; SWITCHCRAFT_PJRAN1X1U0XX
R1, R2, R3, R4: 4.7k; R_Axial_DIN0207_L6.3mm_D2.5mm_P10.16mm_Horizontal
R5: 330; R_Axial_DIN0207_L6.3mm_D2.5mm_P10.16mm_Horizontal
R6: 1k; R_Axial_DIN0207_L6.3mm_D2.5mm_P10.16mm_Horizontal
R7, R8: 820; R_Axial_DIN0207_L6.3mm_D2.5mm_P10.16mm_Horizontal
R9: 10k; R_Axial_DIN0207_L6.3mm_D2.5mm_P10.16mm_Horizontal
SW1: POWER; SW_400MSP1R6BLKM6QE; Digikey EG4326-ND
U1: 74LS04; DIP-14_W7.62mm_Socket_LongPads
U2: 6502; DIP-40_W15.24mm_Socket_LongPads
U3: 65C21; DIP-40_W15.24mm_Socket_LongPads
U4: AS6C62256; DIP-28_W15.24mm_Socket_LongPads
U5: 74LS00; DIP-14_W7.62mm_Socket_LongPads
U6: 74LS138; DIP-16_W7.62mm_Socket_LongPads
U7: 28C64; DIP-28_W15.24mm_Socket_LongPads
U8: 74LS245; DIP-20_W7.62mm_Socket_LongPads
U9: MAX232; DIP-16_W7.62mm_Socket_LongPads; Digikey 296-1402-5-ND
U10: ATmega1284-P; DIP-40_W15.24mm_Socket_LongPads
Y1: 1MHz; Oscillator_DIP-14
Y2: 28.636MHz; Crystal_HC49-U_Vertical; Digikey 887-1256-ND

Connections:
$A000: J1.11, U6.13 (O2)
$B000: J1.21, U6.12 (O3)
$C000: J1.19, U6.11 (O4)
$D000: U3.23 (CS2B), U6.10 (O5)
A0: J1.38, U2.9 (A0), U3.36 (RS0), U4.10 (A0), U7.10 (A0)
A1: J1.36, U2.10 (A1), U3.35 (RS1), U4.9 (A1), U7.9 (A1)
A2: J1.34, U2.11 (A2), U4.8 (A2), U7.8 (A2)
A3: J1.32, U2.12 (A3), U4.7 (A3), U7.7 (A3)
A4: J1.30, U2.13 (A4), U3.22 (CS0), U4.6 (A4), U7.6 (A4)
A5: J1.28, U2.14 (A5), U4.5 (A5), U7.5 (A5)
A6: J1.26, U2.15 (A6), U4.4 (A6), U7.4 (A6)
A7: J1.24, U2.16 (A7), U4.3 (A7), U7.3 (A7)
A8: J1.22, U2.17 (A8), U4.25 (A8), U7.25 (A8)
A9: J1.20, U2.18 (A9), U4.24 (A9), U7.24 (A9)
A10: J1.18, U2.19 (A10), U4.21 (A10), U7.21 (A10)
A11: J1.16, U2.20 (A11), U4.23 (A11), U7.23 (A11)
A12: J1.14, U2.22 (A12), U4.2 (A12), U6.1 (A0), U7.2 (A12)
A13: J1.12, U2.23 (A13), U4.26 (A13), U6.2 (A1)
A14: J1.10, U2.24 (A14), U4.1 (A14), U6.3 (A2)
A15: J1.8, U2.25 (A15), U4.20 (~CE), U4.22 (~OE), U6.6 (E3)
D0: J1.37, U2.33 (D0), U3.33 (D0), U4.11 (DQ0), U7.11 (I/O0)
D1: J1.35, U2.32 (D1), U3.32 (D1), U4.12 (DQ1), U7.12 (I/O1)
D2: J1.33, U2.31 (D2), U3.31 (D2), U4.13 (DQ2), U7.13 (I/O2)
D3: J1.31, U2.30 (D3), U3.30 (D3), U4.15 (DQ3), U7.15 (I/O3)
D4: J1.29, U2.29 (D4), U3.29 (D4), U4.16 (DQ4), U7.16 (I/O4)
D5: J1.27, U2.28 (D5), U3.28 (D5), U4.17 (DQ5), U7.17 (I/O5)
D6: J1.25, U2.27 (D6), U3.27 (D6), U4.18 (DQ6), U7.18 (I/O6)
D7: J1.23, U2.26 (D7), U3.26 (D7), U4.19 (DQ7), U7.19 (I/O7)
DA: U1.2, U3.17 (PB7), U10.8 (PB7)
GND: C1.2, C2.2, C3.2, C4.2, C5.2, C6.2, C7.2, C8.2, C9.2, C10.2, C12.1, C13.1, C15.1, C16.1, C17.2, J1.1, J1.40, J2.9 (GND), J3.5, J3.SH (PAD), J4.2, J4.3, J5.3, J6.2 (Ext), R5.2, R9.1, U1.3, U1.5, U1.7 (GND), U1.9, U1.11, U1.13, U2.1 (VSS), U2.21 (VSS), U3.1 (VSS), U4.14 (GND), U5.7 (GND), U6.4 (E1), U6.5 (E2), U6.8 (GND), U7.14 (GND), U8.10 (GND), U9.8 (R2IN), U9.10 (T2IN), U9.15 (GND), U10.11 (GND), U10.31 (GND), U10.32 (AREF), Y1.7 (GND)
IRQB: J1.5, R1.1, U2.4 (IRQB)
KBD0: J2.5 (B1), U8.2 (A0)
KBD1: J2.4 (B2), U8.3 (A1)
KBD2: J2.3 (B3), U8.4 (A2)
KBD3: J2.2 (B4), U8.5 (A3)
KBD4: J2.6 (B5), U8.6 (A4)
KBD5: J2.7 (B6), U8.7 (A5)
KBD6: J2.8 (B7), U8.8 (A6)
KBDCLR: J2.12 (CLEAR), R9.2, U10.19 (PD5)
KBDENB: U8.19 (CE), U10.20 (PD6)
KBDRESB: J2.1 (RESET), U10.18 (PD4)
KBDSTROBE: J2.14 (STROBE), U8.9 (A7)
NMIB: J1.7, R2.1, U2.6 (NMIB)
unnamed: D1.1 (K), R5.1
unnamed: J6.1 (In), R6.2, R7.2, R8.2
unnamed: J4.1, SW1.2 (B)
unnamed: U1.1, U3.19 (CB2)
unnamed: U4.27 (~WE), U5.11
unnamed: U5.3, U5.4, U5.5
unnamed: U5.8, U5.13
unnamed: U5.1, U6.9 (O6)
unnamed: U5.2, U6.7 (O7)
unnamed: C11.1, U9.1 (C1+)
unnamed: C11.2, U9.3 (C1-)
unnamed: C14.2, U9.4 (C2+)
unnamed: C14.1, U9.5 (C2-)
unnamed: C15.2, U9.2 (VS+)
unnamed: C16.2, U9.6 (VS-)
unnamed: R6.1, U10.22 (PC0)
unnamed: R7.1, U10.23 (PC1)
unnamed: R8.1, U10.24 (PC2)
unnamed: C12.2, U10.13 (XTAL1), Y2.2
unnamed: C13.2, U10.12 (XTAL2), Y2.1
PA0: U3.2 (PA0), U8.18 (B0), U10.40 (PA0)
PA1: U3.3 (PA1), U8.17 (B1), U10.39 (PA1)
PA2: U3.4 (PA2), U8.16 (B2), U10.38 (PA2)
PA3: U3.5 (PA3), U8.15 (B3), U10.37 (PA3)
PA4: U3.6 (PA4), U8.14 (B4), U10.36 (PA4)
PA5: U3.7 (PA5), U8.13 (B5), U10.35 (PA5)
PA6: U3.8 (PA6), U8.12 (B6), U10.34 (PA6)
PB0: U3.10 (PB0), U10.1 (PB0)
PB1: U3.11 (PB1), U10.2 (PB1)
PB2: U3.12 (PB2), U10.3 (PB2)
PB3: U3.13 (PB3), U10.4 (PB3)
PB4: U3.14 (PB4), U10.5 (PB4)
PB5: U3.15 (PB5), U10.6 (PB5)
PB6: U3.16 (PB6), U10.7 (PB6)
PHI0: U2.37 (PHI0), Y1.8 (OUT)
PHI2: J1.17, U2.39 (PHI2), U3.25 (PHI2), U5.12
PS2CLK: J5.5, U10.16 (PD2)
PS2DATA: J5.1, U10.17 (PD3)
RDAB: U3.18 (CB1), U10.29 (PC7)
RDY: J1.9, R3.1, U2.2 (RDY)
REB: U5.6, U7.20 (~CE), U7.22 (~OE)
RESB: J1.3, R4.1, U2.40 (RESB), U3.34 (RESB), U10.21 (PD7)
RWB: J1.13, U2.34 (RWB), U3.21 (RWB), U5.9, U5.10
RX: U9.12 (R1OUT), U10.14 (PD0)
RXIN: J3.2, U9.13 (R1IN)
STROBE: U3.40 (CA1), U8.11 (B7), U10.33 (PA7)
SYNC: J1.15, U2.7 (SYNC)
TX: U9.11 (T1IN), U10.15 (PD1)
TXOUT: J3.3, U9.14 (T1OUT)
VCC: C1.1, C2.1, C3.1, C4.1, C5.1, C6.1, C7.1, C8.1, C9.1, C10.1, C17.1, D1.2 (A), J1.2, J1.39, J2.16 (VCC), J5.4, R1.2, R2.2, R3.2, R4.2, SW1.1 (A), U1.14 (VCC), U2.8 (VDD), U2.38 (SOB), U3.9 (PA7), U3.20 (VDD), U3.24 (CS1), U4.28 (VCC), U5.14 (VCC), U6.16 (VCC), U7.27 (~WE), U7.28 (VCC), U8.1 (A->B), U8.20 (VCC), U9.16 (VCC), U10.9 (~RESET), U10.10 (VCC), U10.30 (AVCC), Y1.14 (Vcc)

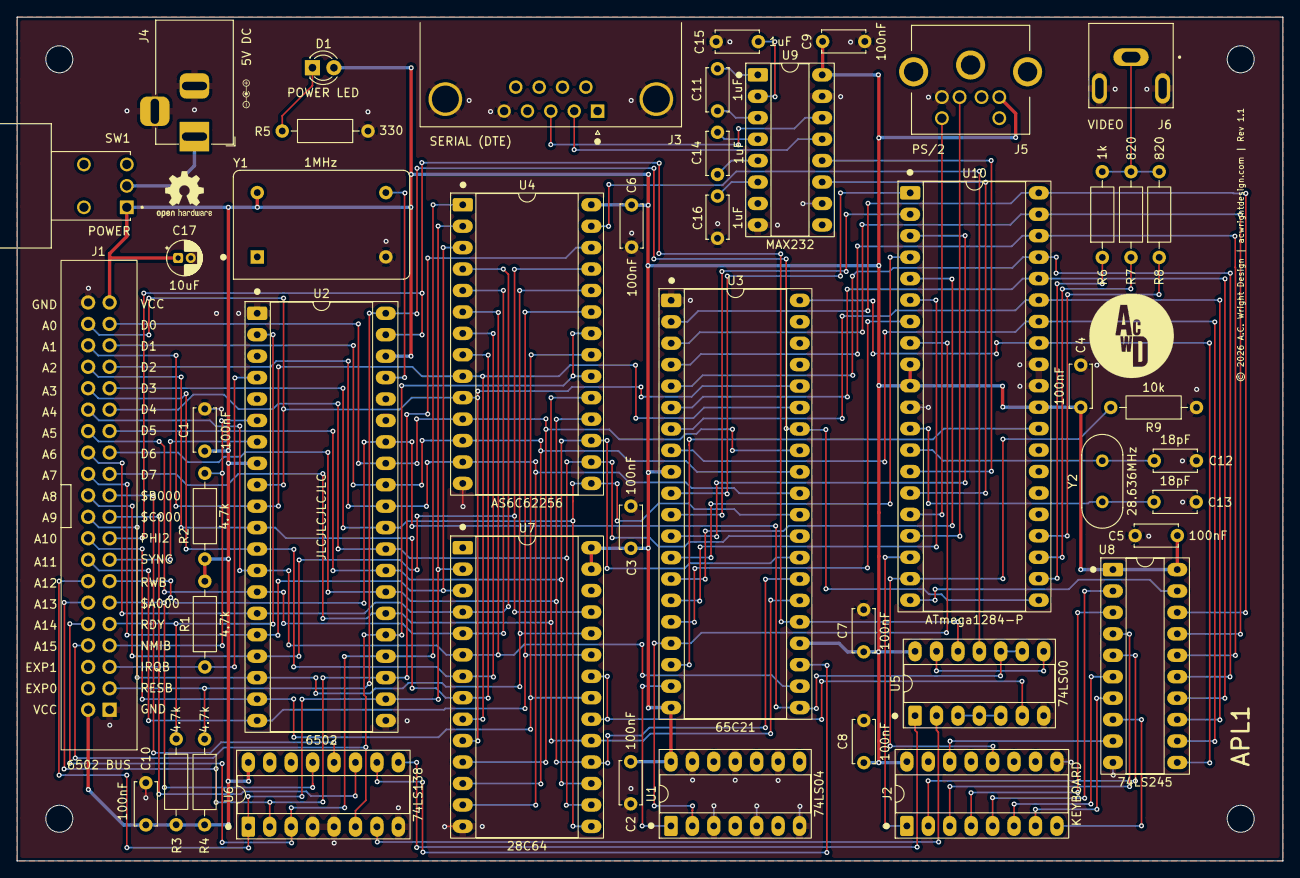
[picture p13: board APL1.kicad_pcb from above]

Board: 2 copper layers, 150.0 x 100.0 mm, 46 parts (0 on the bottom side), 93 nets.

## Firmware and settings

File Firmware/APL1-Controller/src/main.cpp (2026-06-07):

#include <Arduino.h>

// ---------------------------------------------------------------------------
// Port / pin macros
// ---------------------------------------------------------------------------

// PORTA  PA0-6 = keyboard ASCII data to PIA PA0-6; PA7 = STROBE (CA1)
//        Idle = Hi-Z input (driven only while injecting a key)
#define PA_DATA_MASK    0x7F
#define PA_STROBE_BIT   7

// PORTB  PB0-6 = display data from PIA; PB7 = DA (display available)
//        The PIA CB2 handshake output is active-LOW, but it passes through an
//        external 74HC04 inverter (U1) before reaching PB7, so at the ATmega
//        DA is active-HIGH: PB7 HIGH = 6502 has written a char (DA asserted).
#define PB_DISP_MASK    0x7F
#define PB_DA_BIT       7

// PORTC  PC0-2 = video DAC outputs (deferred, kept low)
//        PC3-6 = unused inputs w/ pullup
//        PC7   = RDAB -> CB1 (active-low pulse; idle HIGH)
#define PC_DAC_MASK     0x07
#define PC_RDAB_BIT     7
#define PC_RDAB_LOW()   (PORTC &= ~(1 << PC_RDAB_BIT))
#define PC_RDAB_HIGH()  (PORTC |=  (1 << PC_RDAB_BIT))

// PORTD  PD0=RXD  PD1=TXD  PD2=PS2CLK(INT0)  PD3=PS2DATA
//        PD4=KBDRESB(in,active-low)  PD5=KBDCLR(in,active-HIGH)
//        PD6=KBDENB(out,active-low: LOW=74LS245 enabled)
//        PD7=RESB(out,active-low reset to 6502)
#define PD_RXD_BIT      0
#define PD_TXD_BIT      1
#define PD_PS2CLK_BIT   2
#define PD_PS2DATA_BIT  3
#define PD_KBDRESB_BIT  4
#define PD_KBDCLR_BIT   5
#define PD_KBDENB_BIT   6
#define PD_RESB_BIT     7

#define KBDENB_ENABLE()   (PORTD &= ~(1 << PD_KBDENB_BIT))  // LOW  = 74LS245 enabled
#define KBDENB_DISABLE()  (PORTD |=  (1 << PD_KBDENB_BIT))  // HIGH = buffer disabled

#define RESB_ASSERT()     (PORTD &= ~(1 << PD_RESB_BIT))    // LOW  = 6502 in reset
#define RESB_RELEASE()    (PORTD |=  (1 << PD_RESB_BIT))    // HIGH = 6502 running

// ---------------------------------------------------------------------------
// PS/2 Set-2 scancode tables (US layout -> Apple-1 ASCII, bit7 set)
//   Index = Set-2 make code (0x00-0x7F); 0x00 = no mapping.
//   Letters are always uppercase; shift only affects digits and symbols.
// ---------------------------------------------------------------------------
static const uint8_t PROGMEM ps2_base[128] = {
//  0     1     2     3     4     5     6     7     8     9     A     B     C     D     E     F
    0x00, 0x00, 0x00, 0x00, 0x00, 0x00, 0x00, 0x00, 0x00, 0x00, 0x00, 0x00, 0x00, 0x00, 0xE0, 0x00, // 00  (0x0E=`)
    0x00, 0x00, 0x00, 0x00, 0x00, 0xD1, 0xB1, 0x00, 0x00, 0x00, 0xDA, 0xD3, 0xC1, 0xD7, 0xB2, 0x00, // 10  Q 1 Z S A W 2
    0x00, 0xC3, 0xD8, 0xC4, 0xC5, 0xB4, 0xB3, 0x00, 0x00, 0xA0, 0xD6, 0xC6, 0xD4, 0xD2, 0xB5, 0x00, // 20  C X D E 4 3 Sp V F T R 5
    0x00, 0xCE, 0xC2, 0xC8, 0xC7, 0xD9, 0xB6, 0x00, 0x00, 0x00, 0xCD, 0xCA, 0xD5, 0xB7, 0xB8, 0x00, // 30  N B H G Y 6 M J U 7 8
    0x00, 0xAC, 0xCB, 0xC9, 0xCF, 0xB0, 0xB9, 0x00, 0x00, 0xAE, 0xAF, 0xCC, 0xBB, 0xD0, 0xAD, 0x00, // 40  , K I O 0 9 . / L ; P -
    0x00, 0x00, 0xA7, 0x00, 0xDB, 0xBD, 0x00, 0x00, 0x00, 0x00, 0x8D, 0xDD, 0x00, 0xDC, 0x00, 0x00, // 50  ' [ = Enter ] bksl
    0x00, 0x00, 0x00, 0x00, 0x00, 0x00, 0xDF, 0x00, 0x00, 0x00, 0x00, 0x00, 0x00, 0x00, 0x00, 0x00, // 60  (0x66=Backspace->_)
    0x00, 0x00, 0x00, 0x00, 0x00, 0x00, 0x9B, 0x00, 0x00, 0x00, 0x00, 0x00, 0x00, 0x00, 0x00, 0x00  // 70  (0x76=ESC)
};

static const uint8_t PROGMEM ps2_shifted[128] = {
//  0     1     2     3     4     5     6     7     8     9     A     B     C     D     E     F
    0x00, 0x00, 0x00, 0x00, 0x00, 0x00, 0x00, 0x00, 0x00, 0x00, 0x00, 0x00, 0x00, 0x00, 0xFE, 0x00, // 00  (`->~)
    0x00, 0x00, 0x00, 0x00, 0x00, 0xD1, 0xA1, 0x00, 0x00, 0x00, 0xDA, 0xD3, 0xC1, 0xD7, 0xC0, 0x00, // 10  (1->! 2->@)
    0x00, 0xC3, 0xD8, 0xC4, 0xC5, 0xA4, 0xA3, 0x00, 0x00, 0xA0, 0xD6, 0xC6, 0xD4, 0xD2, 0xA5, 0x00, // 20  (4->$ 3-># 5->%)
    0x00, 0xCE, 0xC2, 0xC8, 0xC7, 0xD9, 0xDE, 0x00, 0x00, 0x00, 0xCD, 0xCA, 0xD5, 0xA6, 0xAA, 0x00, // 30  (6->^ 7->& 8->*)
    0x00, 0xBC, 0xCB, 0xC9, 0xCF, 0xA9, 0xA8, 0x00, 0x00, 0xBE, 0xBF, 0xCC, 0xBA, 0xD0, 0xDF, 0x00, // 40  (,->< 0->) 9->( .-> > /->? ;->: ->>_)
    0x00, 0x00, 0xA2, 0x00, 0xFB, 0xAB, 0x00, 0x00, 0x00, 0x00, 0x8D, 0xFD, 0x00, 0xFC, 0x00, 0x00, // 50  ('->" [->{ =->+ ]->} \->|)
    0x00, 0x00, 0x00, 0x00, 0x00, 0x00, 0xDF, 0x00, 0x00, 0x00, 0x00, 0x00, 0x00, 0x00, 0x00, 0x00, // 60
    0x00, 0x00, 0x00, 0x00, 0x00, 0x00, 0x9B, 0x00, 0x00, 0x00, 0x00, 0x00, 0x00, 0x00, 0x00, 0x00  // 70
};

// PS/2 ring buffer (written by ISR, read by main loop)
#define PS2_BUF_SIZE 16                        // must be a power of 2
static volatile uint8_t ps2_buf[PS2_BUF_SIZE];
static volatile uint8_t ps2_head = 0;          // ISR writes here
static volatile uint8_t ps2_tail = 0;          // main reads here

// ---------------------------------------------------------------------------
// Throttle ("slow") mode
//   Toggled at runtime by Ctrl-T (0x14) over serial.
//   FALSE = full speed (UART-buffered, 6502 barely waits on the DA flag).
//   TRUE  = emulate the original Apple-1 terminal: before clearing the DA
//           flag we keep it asserted for SLOW_CHAR_DELAY_MS, which forces the
//           6502 to spin in WozMon's `BIT DSP / BMI ECHO` loop just as it did
//           against the real video hardware (~60 characters/second).
// ---------------------------------------------------------------------------
#define SLOW_CHAR_DELAY_MS 16                  // ~60 chars/sec, original feel
static bool slowMode = false;

// ---------------------------------------------------------------------------
// putDisplayChar()  (video buffer hook deferred)
// ---------------------------------------------------------------------------
void putDisplayChar(uint8_t c) {
    Serial.write(c);
    // Future: also write to video buffer
}

// ---------------------------------------------------------------------------
// sendKey()  inject one Apple-1 ASCII byte into the PIA
// ---------------------------------------------------------------------------
// ascii : Apple-1 style (bit7 set, uppercase).
//
// The keyboard STROBE (PIA CA1) line is driven, when idle, by the keyboard
// through the 74LS245 (B8). Measured on real hardware the keyboard idles this
// line HIGH, and the PIA is set to latch keyboard data on the RISING edge of
// CA1 (KBDCR = $A7). Injection therefore has to produce EXACTLY ONE rising edge
// on CA1, and must hand the line back to the '245 at the same idle level it
// found it - otherwise the '245 re-asserting the idle HIGH level creates a
// SECOND, phantom rising edge that latches the idle bus value (0x7F -> reads
// 0xFF) which WozMon rejects by echoing "\". That phantom was the bug.
void sendKey(uint8_t ascii) {
    // Capture the keyboard's idle CA1 level while the '245 still drives the bus
    // and PORTA is input. We restore CA1 to this exact level before handing the
    // bus back, making the '245 takeover a same-level (no-edge) transition.
    uint8_t idleHigh = (PINA >> PA_STROBE_BIT) & 1;

    KBDENB_DISABLE();                           // PD6 HIGH – take bus from '245

    // Drive CA1 LOW first, then HIGH, so the latch is one clean rising edge.
    DDRA  = 0xFF;                               // PA all outputs
    PORTA = ascii & PA_DATA_MASK;               // PA0-6 = data; PA7 (CA1) LOW
    delayMicroseconds(2);                       // data setup time
    PORTA |=  (1 << PA_STROBE_BIT);             // CA1 LOW→HIGH: latch injected key
    delayMicroseconds(20);                      // PIA latch hold time

    // Restore CA1 to the keyboard idle level. With idle HIGH we simply hold it
    // HIGH (no further edge). If idle were LOW we drop it (a falling edge, which
    // the PIA ignores). Either way no extra RISING edge is produced.
    if (idleHigh) PORTA |=  (1 << PA_STROBE_BIT);
    else          PORTA &= ~(1 << PA_STROBE_BIT);

    // Release PA0-6 but keep driving CA1 at the idle level during the handoff.
    DDRA  = (1 << PA_STROBE_BIT);               // PA0-6 Hi-Z, PA7 still output
    delayMicroseconds(2);

    KBDENB_ENABLE();                            // PD6 LOW – '245 re-drives CA1 to
                                                // the same idle level: no edge
    delayMicroseconds(2);                       // let the '245 take over CA1

    DDRA  = 0x00;                               // PA back to Hi-Z inputs
    PORTA = 0x00;
}

// ---------------------------------------------------------------------------
// PS/2 frame ISR  (INT0, triggered on falling edge of PS2CLK/PD2)
//   11-bit frame: start(0) | D0..D7 LSB-first | parity(odd) | stop(1)
// ---------------------------------------------------------------------------
ISR(INT0_vect) {
    static uint16_t sr  = 0;   // 11-bit shift register (bit 0 = first received)
    static uint8_t  cnt = 0;   // counts received bits (0..10)

    // Shift in data bit sampled on the falling clock edge
    sr |= (uint16_t)((PIND >> PD_PS2DATA_BIT) & 1) << cnt;

    if (++cnt == 11) {
        // Validate: start=0, stop=1, odd parity over 9-bit field (data + parity)
        if (!(sr & 1) &&                             // start bit must be 0
            ((sr >> 10) & 1) &&                      // stop  bit must be 1
            __builtin_parity((sr >> 1) & 0x1FF)) {   // 8 data + 1 parity = odd
            uint8_t byte = (uint8_t)(sr >> 1);
            uint8_t next = (ps2_head + 1) & (PS2_BUF_SIZE - 1);
            if (next != ps2_tail) {                  // drop if buffer full
                ps2_buf[ps2_head] = byte;
                ps2_head = next;
            }
        }
        sr  = 0;
        cnt = 0;
    }
}

// ---------------------------------------------------------------------------
// PS/2 scancode decoder  (Set-2, stateful)
// ---------------------------------------------------------------------------
static uint8_t ps2_state = 0;  // 0=normal 1=F0-break 2=E0-ext 3=E0-F0-ext-break
static uint8_t ps2_mods  = 0;  // bit0=shift  bit1=ctrl  bit2=alt

// Called by KBDRESB handler to clear decoder state
static inline void resetPS2State() { ps2_state = 0; ps2_mods = 0; }

// Forward declarations (defined after processPS2)
static void clearScreen();
static void doReset();

static void processPS2(uint8_t sc) {
    uint8_t &state = ps2_state;
    uint8_t &mods  = ps2_mods;

    switch (state) {
        case 0:  // --- normal: watch for prefix bytes or process make code ---
            if      (sc == 0xF0) { state = 1; return; }
            else if (sc == 0xE0) { state = 2; return; }
            // Modifier make events
            if (sc == 0x12 || sc == 0x59) { mods |=  0x01; return; }  // L/R Shift
            if (sc == 0x14)               { mods |=  0x02; return; }  // L Ctrl
            if (sc == 0x11)               { mods |=  0x04; return; }  // L Alt
            if (sc == 0x58) return;                                    // Caps Lock: ignored
            // Ctrl+L -> clear screen; Ctrl+\ -> reset 6502; Ctrl+T -> toggle
            // throttle (consume, do not forward)
            if (sc == 0x4B && (mods & 0x02)) { clearScreen(); return; }
            if (sc == 0x5D && (mods & 0x02)) { doReset();     return; }
            if (sc == 0x2C && (mods & 0x02)) { slowMode = !slowMode; return; }
            {
                uint8_t ascii = (sc < 128)
                    ? ((mods & 0x01)
                        ? pgm_read_byte(&ps2_shifted[sc])
                        : pgm_read_byte(&ps2_base[sc]))
                    : 0;
                if (ascii) sendKey(ascii);
            }
            break;

        case 1:  // --- F0 break: release event ---
            state = 0;
            if (sc == 0x12 || sc == 0x59) mods &= ~0x01;  // L/R Shift release
            if (sc == 0x14)               mods &= ~0x02;  // L Ctrl release
            if (sc == 0x11)               mods &= ~0x04;  // L Alt release
            break;

        case 2:  // --- E0 extended make ---
            if (sc == 0xF0) { state = 3; return; }         // E0 F0 break follows
            state = 0;
            if (sc == 0x14) { mods |=  0x02; return; }  // R Ctrl make (E0 14)
            if (sc == 0x11) { mods |=  0x04; return; }  // R Alt  make (E0 11)
            // Ctrl+Alt+Del -> reset 6502 (consume key)
            if (sc == 0x71 && (mods & 0x06) == 0x06) { doReset(); return; }
            break;

        case 3:  // --- E0 F0 extended break ---
            state = 0;
            if (sc == 0x14) mods &= ~0x02;  // R Ctrl release (E0 F0 14)
            if (sc == 0x11) mods &= ~0x04;  // R Alt  release (E0 F0 11)
            break;
    }
}

// ---------------------------------------------------------------------------
// clearScreen() / doReset()  (shared by KBDCLR, PS/2, serial)
// ---------------------------------------------------------------------------
static void clearScreen() {
    // ANSI ESC[2J = erase display, ESC[;H = cursor home (matches CoolTerm "Home display" pattern; valid VT100)
    Serial.print(F("\x1B[2J\x1B[;H"));
    // Future: also clear video framebuffer
}

static void doReset() {
    resetPS2State();
    RESB_ASSERT();
    delay(10);          // 6502 reset pulse (≥2 clock cycles; 10 ms comfortable)
    RESB_RELEASE();
}

// ---------------------------------------------------------------------------
// setup()
// ---------------------------------------------------------------------------
void setup() {
    // --- PORTA: all inputs, no pullups (Hi-Z) until key injection ---
    DDRA  = 0x00;
    PORTA = 0x00;

    // --- PORTB: all inputs. DA (PB7) is driven by the 74HC04 (U1) output, so no
    //     pull-up is used: an internal pull-up would force PB7 HIGH and, because
    //     DA is active-HIGH here, register as a permanent (false) DA assertion.
    DDRB  = 0x00;
    PORTB = 0x00;               // no pull-ups; U1 actively drives DA, PIA drives PB0-6

    // --- PORTC ---
    // PC0-2 = outputs (video DAC, deferred), drive LOW
    // PC3-6 = unused inputs with pullup (defined state)
    // PC7   = output, idle HIGH (RDAB)
    DDRC  = (1 << PC_RDAB_BIT) | PC_DAC_MASK;    // 0x87
    PORTC = (1 << PC_RDAB_BIT)                    // RDAB idle HIGH
          | (1 << 3) | (1 << 4) | (1 << 5) | (1 << 6); // PC3-6 pullups; 0xF8 total

    // --- PORTD ---
    // PD0 = RXD input  (UART)
    // PD1 = TXD output (UART)
    // PD2-5 = inputs; PS2CLK, PS2DATA, KBDRESB have pullup; KBDCLR has NO pullup
    //   (KBDCLR is active-HIGH: idle LOW, goes HIGH when key pressed)
    // PD6 = KBDENB output, start LOW (74LS245 buffer enabled)
    // PD7 = RESB  output, start LOW (6502 held in reset)
    DDRD  = (1 << PD_TXD_BIT) | (1 << PD_KBDENB_BIT) | (1 << PD_RESB_BIT); // 0xC2
    PORTD = (1 << PD_PS2CLK_BIT) | (1 << PD_PS2DATA_BIT)
          | (1 << PD_KBDRESB_BIT);
    // KBDCLR (PD5) = 0 → no pullup; PD6 (KBDENB) = 0 → enabled; PD7 (RESB) = 0 → 6502 in reset  (0x1C)

    Serial.begin(115200);   // init UART before releasing 6502 reset

    // --- Power-on reset: hold RESB low, then release ---
    delay(10);       // 10 ms – allows supply rails to stabilise
    RESB_RELEASE();  // PD7 HIGH – release 6502 from reset

    // --- PS/2: INT0 on PD2 falling edge ---
    EICRA = (EICRA & ~0x03) | (1 << ISC01);   // ISC01=1, ISC00=0 = falling edge
    EIMSK |= (1 << INT0);                      // enable INT0
}

// ---------------------------------------------------------------------------
// loop()
// ---------------------------------------------------------------------------
void loop() {
    // --- Display path (PIA -> serial) ---
    // DA is active-HIGH at the ATmega (PIA CB2 is active-low but inverted by U1):
    // PB7 HIGH means the 6502 has written a char to the PIA.
    if (PINB & (1 << PB_DA_BIT)) {
        uint8_t c = PINB & PB_DISP_MASK;       // read PB0-6 (bit7 = DA, ignored)

        // Throttle mode: leave DA asserted so the 6502 keeps spinning in its
        // output-polling loop, replicating the original terminal's slow rate.
        if (slowMode) {
            delay(SLOW_CHAR_DELAY_MS);
        }

        // Acknowledge: pulse RDAB (CB1) low to clear the DA flag in the PIA
        PC_RDAB_LOW();
        delayMicroseconds(20);  // >1 PIA E-clock cycle; was 5 µs (too marginal)
        PC_RDAB_HIGH();

        // Apple-1 always sends 7-bit ASCII; translate bare CR -> CRLF for serial
        if (c == 0x0D) {
            putDisplayChar('\r');
            putDisplayChar('\n');
        } else {
            putDisplayChar(c);
        }
    }

    // --- Serial input (PC -> PIA) ---
    if (Serial.available()) {
        uint8_t c = (uint8_t)Serial.read();
        // Ctrl+L (0x0C FF) -> clear screen; Ctrl+\ (0x1C FS) -> reset 6502
        // Ctrl+T (0x14 DC4) -> toggle throttle (full speed <-> original feel)
        if (c == 0x0C) { clearScreen(); }
        else if (c == 0x1C) { doReset(); }
        else if (c == 0x14) { slowMode = !slowMode; }
        else {
            if (c >= 'a' && c <= 'z') c -= 32;  // force uppercase
            c |= 0x80;                           // set bit 7 (Apple-1 style)
            sendKey(c);
        }
    }

    // --- PS/2 input ---
    if (ps2_tail != ps2_head) {
        uint8_t sc = ps2_buf[ps2_tail];
        ps2_tail = (ps2_tail + 1) & (PS2_BUF_SIZE - 1);
        processPS2(sc);
    }

    // --- Control signals (KBDRESB active-low / KBDCLR active-high, debounced) ---
    // Integrating debounce: each input must remain CONTINUOUSLY in its active
    // state for the whole window before firing. Any single sample in the
    // inactive state re-arms (resets) the timer, so brief noise glitches – e.g.
    // crosstalk coupled onto the keyboard ribbon's RESET line while the PA bus
    // and 74LS245 are switching during heavy serial/key-injection traffic – can
    // no longer accumulate into a spurious reset or clear. A genuine button
    // press is held far longer than the window, so usability is unaffected.
    // NOTE: KBDCLR (PD5) requires an external ~10 kΩ pull-down resistor to GND.
    //       Without it the pin floats HIGH and button presses cannot be detected.
    {
        const uint16_t  KBD_DEBOUNCE_MS = 40;   // continuous active time required
        static bool     resb_armed = false, clr_armed = false;
        static uint32_t resb_t     = 0,     clr_t     = 0;

        uint8_t  resb   = (PIND >> PD_KBDRESB_BIT) & 1;   // active LOW
        uint8_t  clr    = (PIND >> PD_KBDCLR_BIT)  & 1;   // active HIGH
        uint32_t now_ms = millis();

        // KBDRESB: must read LOW on every sample across the whole window
        if (resb) {
            resb_armed = false;                          // released / glitch -> re-arm
        } else if (!resb_armed) {
            resb_armed = true;  resb_t = now_ms;
        } else if (now_ms - resb_t >= KBD_DEBOUNCE_MS) {
            resb_armed = false;
            doReset();
        }

        // KBDCLR: must read HIGH on every sample across the whole window
        if (!clr) {
            clr_armed = false;
        } else if (!clr_armed) {
            clr_armed = true;   clr_t = now_ms;
        } else if (now_ms - clr_t >= KBD_DEBOUNCE_MS) {
            clr_armed = false;
            clearScreen();
        }
    }
}

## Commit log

2026-05-26 Update to schematic
    [APL1.kicad_sch]
2026-05-27 Layout PCB
    [0702461201.step, 228-1277-00-0602J.step, 5-5530843-4.step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]
2026-05-28 Finish PCB
    [APL1.kicad_pcb, APL1.kicad_sch, bom.csv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]
2026-05-28 Update schematic
2026-06-02 Add APL1 Controller firmware
    [fuses.cfg]
2026-06-04 Finish firmware and add README and manuals
    [Wozmon.cfg]
2026-06-06 CAD for base
2026-06-07 Change KBDCLRB to KBDCLR (active high)
    [APL1.kicad_pcb, APL1.kicad_sch, bom.csv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]
2026-06-07 Add R9 to BOM
2026-06-07 Firmware fix for 74HCT245 handling
    [main.cpp]
2026-06-08 Update firmware folder names
    [Wozmon.cfg, fuses.cfg]
2026-06-08 Track build assets (icon) in git; fix missing icon in CI builds
2026-06-15 Fix silkscreen and add bulk capacitance
    [APL1.kicad_pcb, APL1.kicad_sch, APL1.step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]
2026-06-18 Add Rev 1.1
    [APL1.kicad_pcb, APL1.kicad_sch, APL1.step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]
2026-07-06 Switch to local distribution builds; add Windows target
    - Remove GitHub Actions release workflow
    - Add Windows (NSIS x64) target to electron-builder.yml
    - Add dist:win script and update dist to cover all three platforms
    - Remove publish block from electron-builder.yml (manual GitHub release)
    - Consistent artifact naming across mac/win/linux targets
    - Update READMEs with local build prerequisites and instructions

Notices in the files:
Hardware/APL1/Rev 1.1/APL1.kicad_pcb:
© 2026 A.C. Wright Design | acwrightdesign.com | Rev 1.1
